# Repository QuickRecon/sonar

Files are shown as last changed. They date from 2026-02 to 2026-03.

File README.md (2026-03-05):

# Sonar



SonarMK2 is a standalone underwater sonar imaging system. An ESP32 drives a Blue Robotics Ping360 mechanical scanning sonar over RS-485, reads depth from a pressure sensor, and hosts a WiFi access point that serves a real-time polar sonar display to any browser that connects. The ESP hosts a webserver and "realtime" data is streamed over websockets, the page also uses the browser datastore to record the sonar information which can be downloaded and replayed using [text](Firmware/tools/replay.html). There is eventual intention to use the sonar for SLAM and some data analysis has occured in that direction, however this is ongoing.

## Hardware


The core is an ESP32-WROOM-32 with 2 MB flash and no PSRAM. The Ping360 communicates at 115200 baud over a half-duplex RS-485 link with automatic direction control on the DE pin. Depth comes from an MS5837-30BA pressure sensor on I2C at 400 kHz. Four status LEDs give a visual indicator of where the device is in its startup sequence.

Power input is from a battery connector (7–12 V) or USB-C, with an auto-select mux (TPS2121) handling the switch. A boost converter generates the 12 V rail for the sonar; a separate 5 V rail powers the RS-485 and external connectors. Both rails are software-controlled, so the firmware brings them up in sequence and checks power-good signals before proceeding.

The PCB also includes a CAN bus transceiver (TCAN334), the intended use is to allow for expansion to either DPV control/monitoring, or to be attached to a DiveCAN system so that rebreather information can be shown on the same display.

The hardware design files are in `EDA/` (KiCad schematic and PCB) and `CAD/` (FreeCAD housing assembly with STEP exports).

## Firmware

The firmware is built on ESP-IDF v6.0.0 and organized into nine components with no upward dependencies:

- **rs485** — UART1 half-duplex driver with automatic DE control
- **ping_protocol** — Binary frame encoder and decoder, pure C with no ESP-IDF coupling
- **ping360** — Scan task, configuration management, device probing
- **ms5837** — I2C pressure and depth sensor with full second-order compensation
- **led** — Four status LEDs indicating boot progress
- **power** — Rail enable/disable and battery voltage ADC
- **canbus** — CAN bus init and send (scaffolded, not called from main, will eventually have DiveCAN layer)
- **wifi_ap** — WiFi access point with captive portal DNS
- **web_server** — HTTPS file serving and WebSocket broadcast



### TLS Certificates

The web server uses HTTPS with a self-signed certificate. Generate the cert and key before building:

```bash
mkdir -p Firmware/certs
openssl req -x509 -newkey ec -pkeyopt ec_paramgen_curve:prime256v1 \
  -keyout Firmware/certs/server.key -out Firmware/certs/server.pem \
  -days 3650 -nodes -subj "/CN=sonar.local"
```

These files are gitignored — each device should have its own keypair.

The layering is intentional. `ping_protocol` can be compiled and tested on a host machine without any embedded toolchain. `ping360` depends on `rs485` and `ping_protocol` but knows nothing about networking. `web_server` reaches into `ping360` only for config get/set. This keeps the components independently testable and prevents the kind of circular dependency that becomes painful as a codebase grows.

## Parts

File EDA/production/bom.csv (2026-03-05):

Designator | Footprint | Quantity | Value | LCSC Part #
C1, C12, C7 | 0402 | 3 | 100n | C1525
C10, C13 | 0805 | 2 | 4.7u | C1779
C11, C16, C5 | 0603 | 3 | 10u | C96446
C14, C15 | 0402 | 2 | 100p | C1546
C17, C18, C19, C2, C6, C8, C9 | 0603 | 7 | 100n | C14663
C3, C4 | 0805 | 2 | 2.2u | C377773
D1, D2, D3, D4 | 0805 | 4 | LED | C84256
D5 | SOT-23 | 1 | PESD15VS2UT | C2831524
D6 | D_SOD-123 | 1 | MBR0520 | C5204745
F1 | Fuseholder_Littelfuse_Nano2_154x | 1 | 2A | C108518
JP1 | SolderJumper-3_P1.3mm_Bridged2Bar12_RoundedPad1.0x1.5mm | 1 | RE_MODE
L1 | L_SunItech_SLO0530H | 1 | 10u | C325966
Q1, Q2, Q4 | SOT-23 | 3 | SS8050 | C2150
Q3, Q6 | SOT-23 | 2 | SI2302 | C382300
Q5 | TSOT-23 | 1 | SI2301CDS | C10487
R1, R2, R3, R4, R9 | 0402 | 5 | 2k | C4109
R10, R12, R15, R17, R24, R26, R7, R8 | 0402 | 8 | 100k | C25741
R11, R13, R14, R16, R18, R19, R20, R5, R6 | 0402 | 9 | 10k | C25744
R21, R27 | 0402 | 2 | 12k | C25752
R22, R28, R29 | 0402 | 3 | 1.2k | C25862
R23 | 0402 | 1 | 15k | C25756
R25 | 0805 | 1 | 560 | C28636
R30 | 0603 | 1 | 2M | C22976
R31 | 0603 | 1 | 680k | C25822
U1 | QFN-28-1EP_5x5mm_P0.5mm_EP3.35x3.35mm | 1 | CP2102N-Axx-xQFN28 | C6568
U2 | Texas_VQFN-HR-12_2x2.5mm_P0.5mm | 1 | TPS2121
U3 | ESP32-WROOM-32 | 1 | ESP32-WROOM-32 | C701342
U4 | WSON-6-1EP_2x2mm_P0.65mm_EP1x1.6mm_ThermalVias | 1 | TPS7A2550DRVR | C2876265
U5 | TO-263-3_TabPin2 | 1 | LM1085-3.3 | C444380
U6 | SOT-23-5 | 1 | LMR62014XMF | C468235
U7 | SOIC-8_3.9x4.9mm_P1.27mm | 1 | TCAN334 | C2871143
U8 | SOIC-8_3.9x4.9mm_P1.27mm | 1 | ST485EBDR | C81186
U9 | TE_MS5837-xxBA | 1 | MS5837-30BA | C2887941

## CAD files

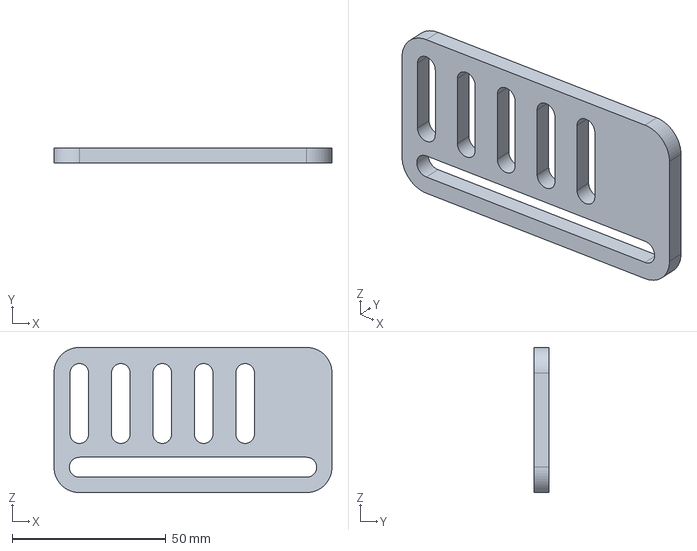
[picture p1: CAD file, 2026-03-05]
CAD/Housing.FCStd
90.5 x 5.00 x 47.2 mm

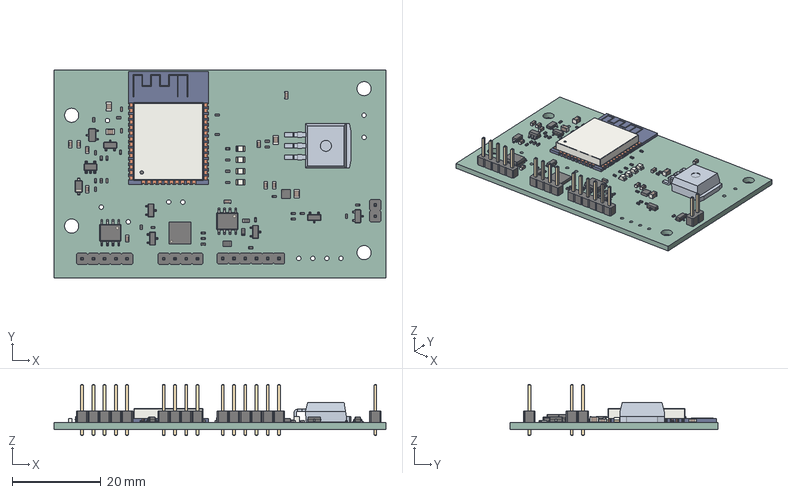
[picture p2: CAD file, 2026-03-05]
EDA/SonarMK2.step
74.9 x 47.0 x 11.5 mm
R_0402_1005Metric x 28
ESP32-WROOM-32
C_0603_1608Metric x 10
R_0805_2012Metric
LED_0805_2012Metric x 4
C_0805_2012Metric x 4
C_0402_1005Metric x 5
R_0603_1608Metric x 2
PinHeader_1x05_P2.54mm_Vertical
SOT-23 x 6
D_SOD-123
SOIC-8_3.9x4.9mm_P1.27mm x 2
TSOT-23
WSON-6-1EP_2x2mm_P0.65mm_EP1x1.6mm
PinHeader_1x06_P2.54mm_Vertical
QFN-28-1EP_5x5mm_P0.5mm_EP3.35x3.35mm
PinHeader_1x02_P2.54mm_Vertical
SonarMK2 1.64.1
SOT-23-5
PinHeader_1x04_P2.54mm_Vertical
SonarMK2_PCB

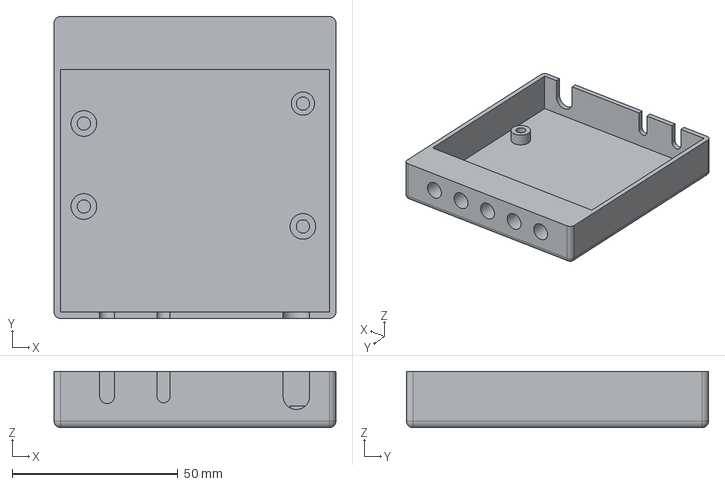
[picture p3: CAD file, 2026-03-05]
CAD/Housing-Body.step
84.9 x 91.0 x 17.0 mm

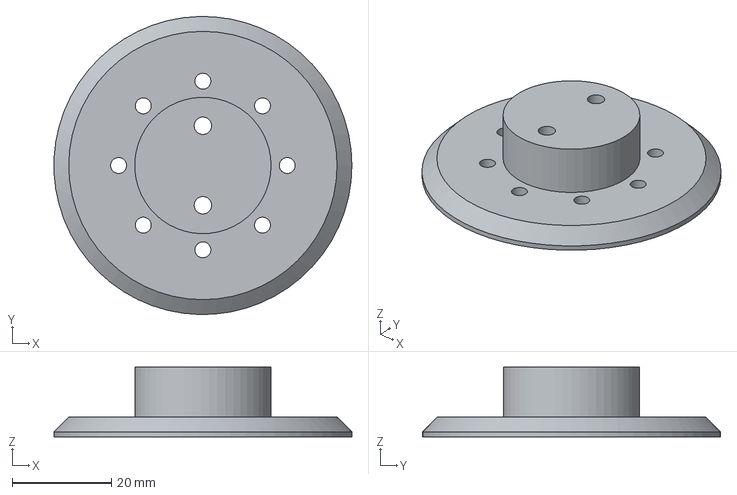
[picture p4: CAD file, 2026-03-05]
CAD/Housing-LefeetSonarMount.step
60.0 x 60.0 x 14.0 mm

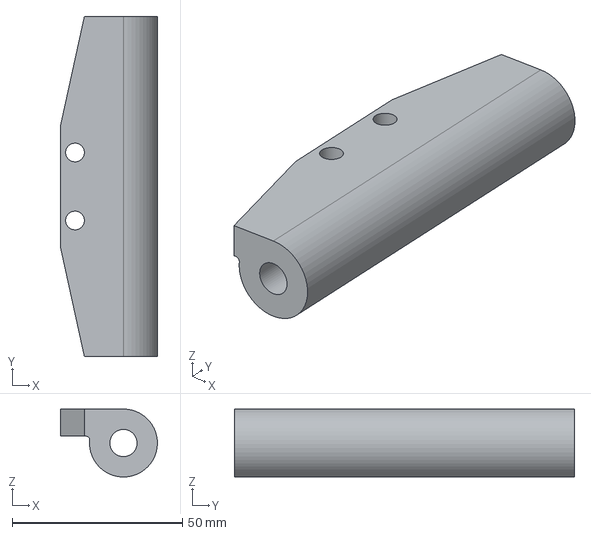
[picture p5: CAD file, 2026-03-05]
CAD/Housing-Sonar Mount.step
28.5 x 100.0 x 20.0 mm

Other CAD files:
CAD/Housing-Sideplate.step

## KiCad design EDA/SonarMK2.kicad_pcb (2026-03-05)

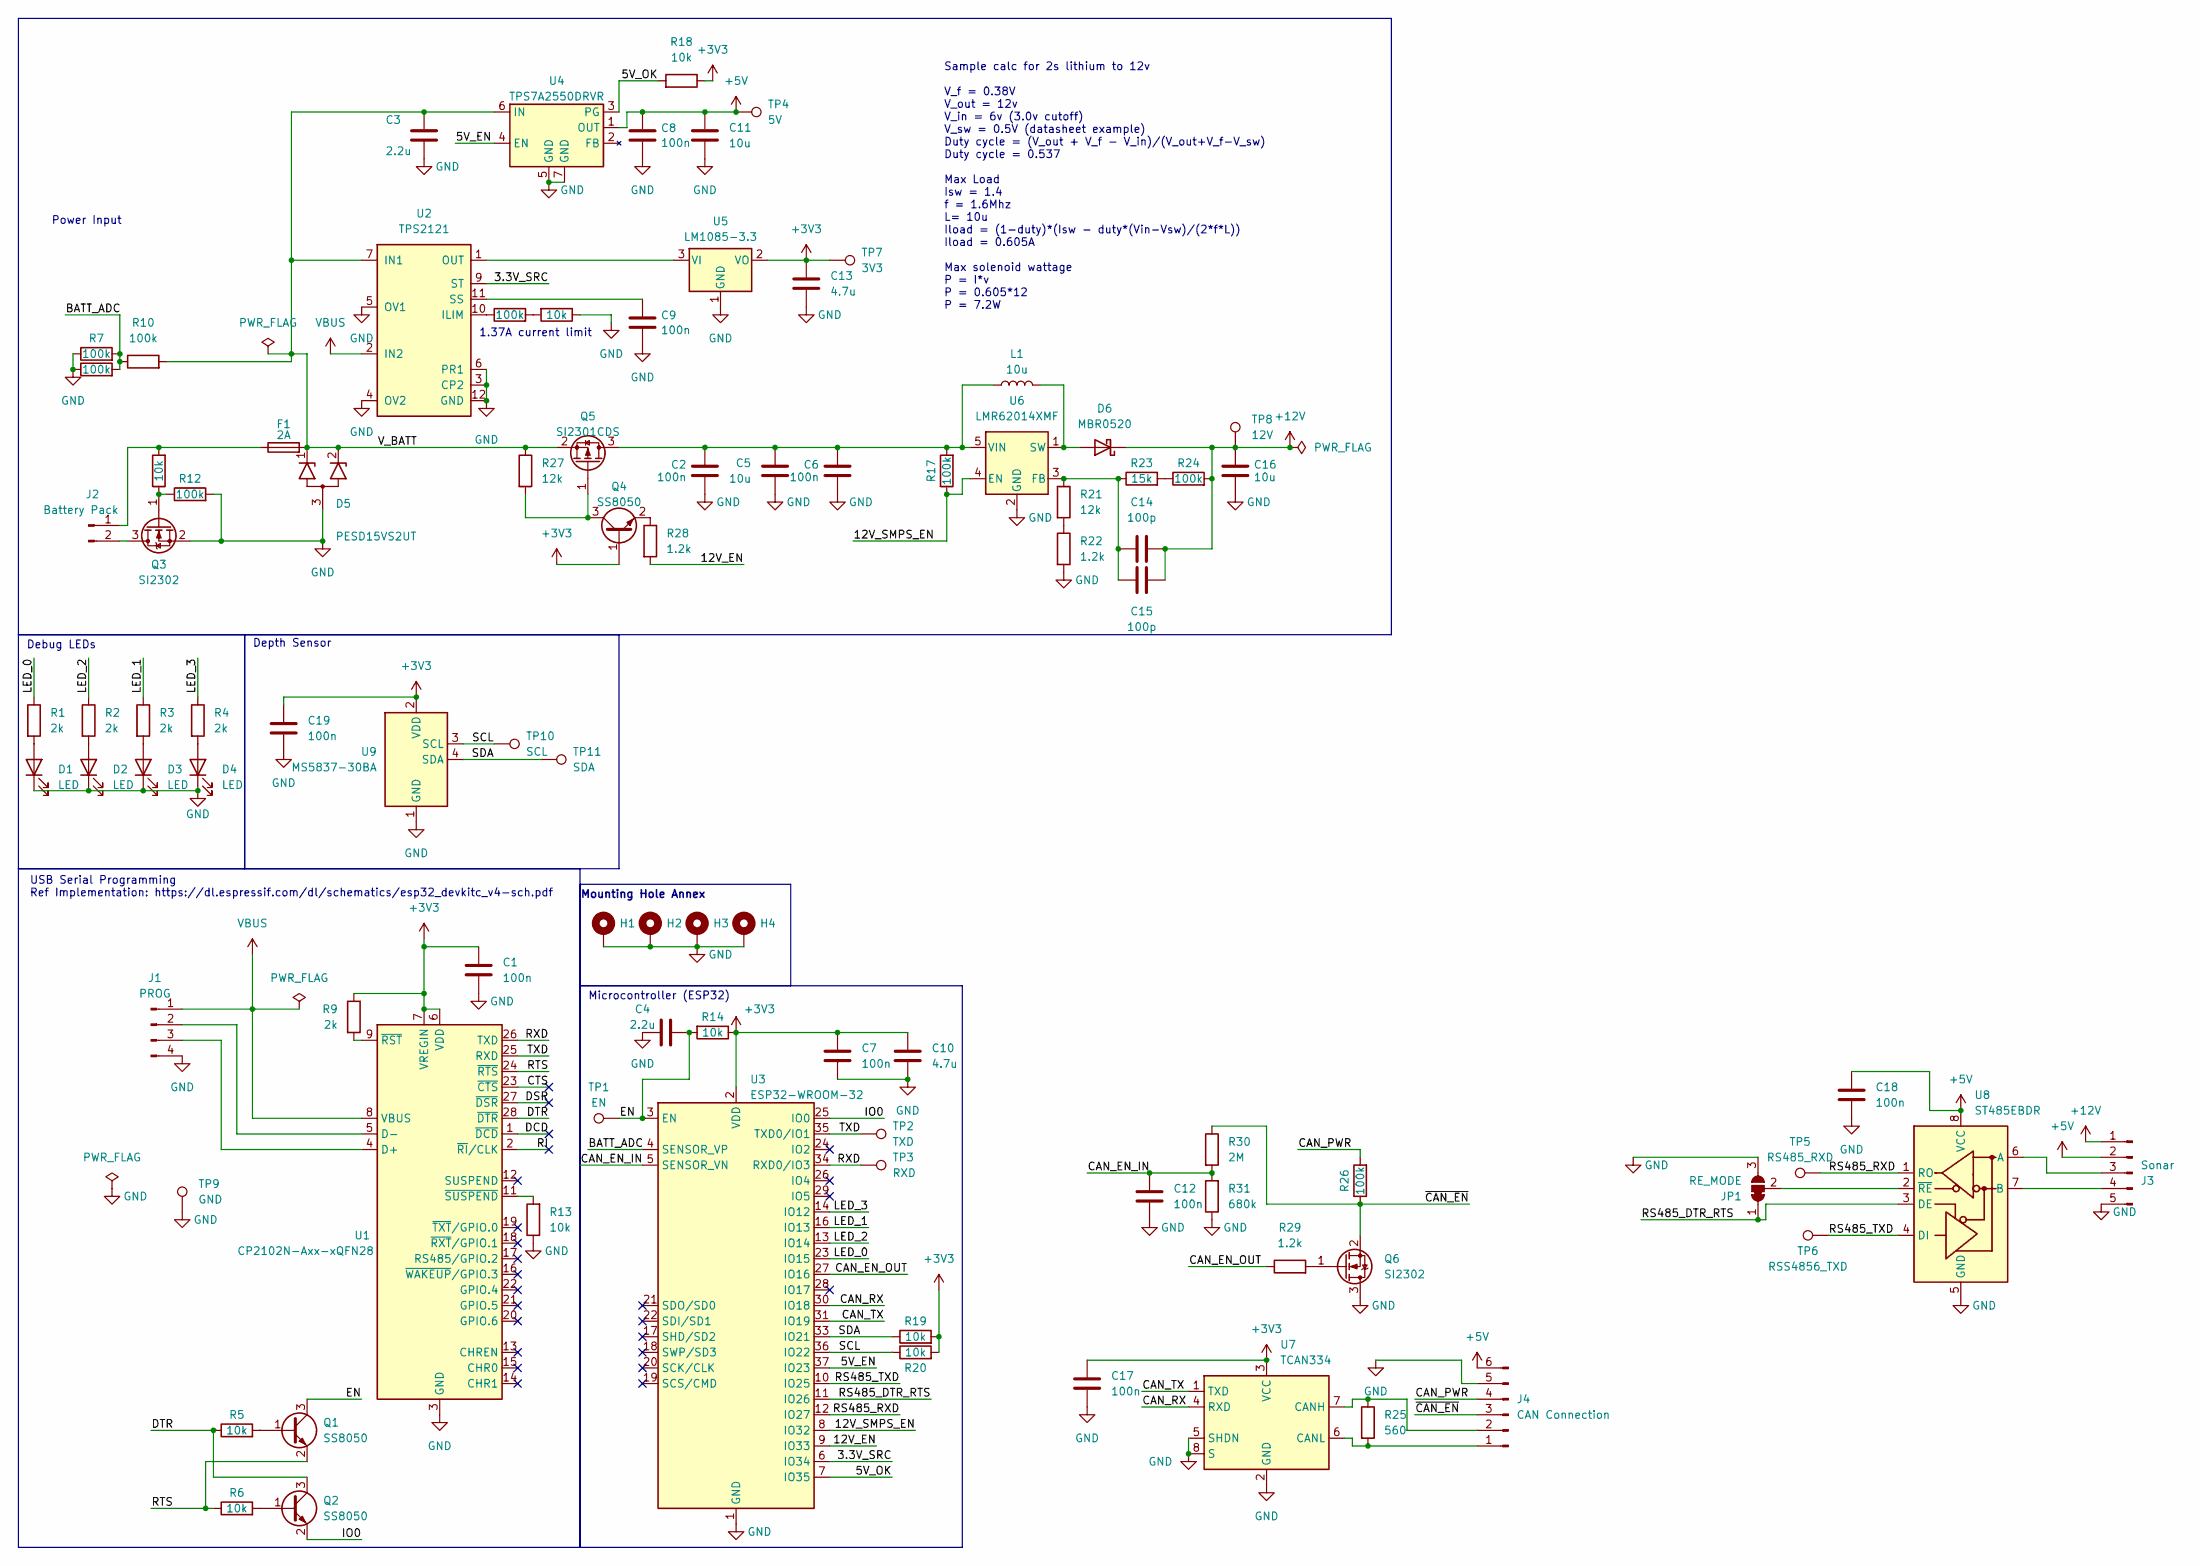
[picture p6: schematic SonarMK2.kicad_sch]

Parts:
C1, C7, C12: 100n; C_0402_1005Metric; MPN C1525
C2, C6, C8, C9, C17, C18, C19: 100n; C_0603_1608Metric; MPN C14663
C3, C4: 2.2u; C_0805_2012Metric; MPN C377773
C5, C11, C16: 10u; C_0603_1608Metric; MPN C96446
C10, C13: 4.7u; C_0805_2012Metric; MPN C1779
C14, C15: 100p; C_0402_1005Metric; MPN C1546
D1, D2, D3, D4: LED; LED_0805_2012Metric; MPN C84256
D5: PESD15VS2UT; SOT-23; MPN C2831524
D6: MBR0520; D_SOD-123; MPN C5204745
F1: 2A; Fuseholder_Littelfuse_Nano2_154x; MPN C108518
H1, H2, H3, H4: MountingHole_Pad; MountingHole_3.2mm_M3_Pad
J1: PROG; PinHeader_1x04_P2.54mm_Vertical
J2: Battery Pack; PinHeader_1x02_P2.54mm_Vertical
J3: Sonar; PinHeader_1x05_P2.54mm_Vertical
J4: CAN Connection; PinHeader_1x06_P2.54mm_Vertical
JP1: RE_MODE; SolderJumper-3_P1.3mm_Bridged2Bar12_RoundedPad1.0x1.5mm
L1: 10u; L_SunItech_SLO0530H; MPN C325966
Q1, Q2, Q4: SS8050; SOT-23; MPN C2150
Q3, Q6: SI2302; SOT-23; MPN C382300; JlcRotOffset 180
Q5: SI2301CDS; TSOT-23; MPN C10487
R1, R2, R3, R4, R9: 2k; R_0402_1005Metric; MPN C4109
R5, R6, R11, R13, R14, R16, R18, R19, R20: 10k; R_0402_1005Metric; MPN C25744
R7, R8, R10, R12, R15, R17, R24, R26: 100k; R_0402_1005Metric; MPN C25741
R21, R27: 12k; R_0402_1005Metric; MPN C25752
R22, R28, R29: 1.2k; R_0402_1005Metric; MPN C25862
R23: 15k; R_0402_1005Metric; MPN C25756
R25: 560; R_0805_2012Metric; MPN C28636
R30: 2M; R_0603_1608Metric; MPN C22976
R31: 680k; R_0603_1608Metric; MPN C25822
TP1: EN; TestPoint_THTPad_2.0x2.0mm_Drill1.0mm
TP2: TXD; TestPoint_THTPad_2.0x2.0mm_Drill1.0mm
TP3: RXD; TestPoint_THTPad_2.0x2.0mm_Drill1.0mm
TP4: 5V; TestPoint_THTPad_2.0x2.0mm_Drill1.0mm
TP5: RS485_RXD; TestPoint_THTPad_2.0x2.0mm_Drill1.0mm
TP6: RSS4856_TXD; TestPoint_THTPad_2.0x2.0mm_Drill1.0mm
TP7: 3V3; TestPoint_THTPad_2.0x2.0mm_Drill1.0mm
TP8: 12V; TestPoint_THTPad_2.0x2.0mm_Drill1.0mm
TP9: GND; TestPoint_THTPad_2.0x2.0mm_Drill1.0mm
TP10: SCL; TestPoint_THTPad_2.0x2.0mm_Drill1.0mm
TP11: SDA; TestPoint_THTPad_2.0x2.0mm_Drill1.0mm
U1: CP2102N-Axx-xQFN28; QFN-28-1EP_5x5mm_P0.5mm_EP3.35x3.35mm; MPN C6568
U2: TPS2121; Texas_VQFN-HR-12_2x2.5mm_P0.5mm; JLC Part # C485916
U3: ESP32-WROOM-32; MPN C701342
U4: TPS7A2550DRVR; WSON-6-1EP_2x2mm_P0.65mm_EP1x1.6mm_ThermalVias; MPN C2876265; JlcRotOffset 0
U5: LM1085-3.3; TO-263-3_TabPin2; MPN C444380
U6: LMR62014XMF; SOT-23-5; MPN C468235
U7: TCAN334; SOIC-8_3.9x4.9mm_P1.27mm; MPN C2871143; JlcRotOffset -90
U8: ST485EBDR; SOIC-8_3.9x4.9mm_P1.27mm; MPN C81186
U9: MS5837-30BA; TE_MS5837-xxBA; MPN C2887941

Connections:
+3V3: C1.1, C7.1, C10.1, C13.1, C17.1, C19.1, Q4.1 (B), R9.1, R14.1, R18.1, R19.2, R20.2, TP7.1, U1.6 (VDD), U1.7 (VREGIN), U3.2 (VDD), U5.2 (VO), U7.3 (VCC), U9.2 (VDD)
+5V: C8.1, C11.1, C18.1, J3.2, J4.6, TP4.1, U4.1 (OUT), U8.8 (VCC)
+12V: C14.1, C15.1, C16.1, D6.1 (K), J3.1, R24.2, TP8.1
/3.3V_SRC: U2.9 (ST), U3.6 (IO34)
/5V_EN: U3.37 (IO23), U4.4 (EN)
/5V_OK: R18.2, U3.7 (IO35), U4.3 (PG)
/12V_EN: R28.2, U3.9 (IO33)
/12V_SMPS_EN: R17.1, U3.8 (IO32), U6.4 (EN)
/BATT_ADC: R7.2, R8.2, R10.1, U3.4 (SENSOR_VP)
/CAN_EN_IN: C12.1, R30.2, R31.2, U3.5 (SENSOR_VN)
/CAN_EN_OUT: R29.1, U3.27 (IO16)
/CAN_PWR: J4.4, R26.2
/CAN_RX: U3.30 (IO18), U7.4 (RXD)
/CAN_TX: U3.31 (IO19), U7.1 (TXD)
/CTS: U1.23 (~CTS)
/DCD: U1.1 (~DCD)
/DSR: U1.27 (~DSR)
/DTR: Q2.3 (C), R5.1, U1.28 (~DTR)
/EN: C4.2, Q1.3 (C), R14.2, TP1.1, U3.3 (EN)
/IO0: Q2.2 (E), U3.25 (IO0)
/LED_0: R1.1, U3.23 (IO15)
/LED_1: R3.1, U3.16 (IO13)
/LED_2: R2.1, U3.13 (IO14)
/LED_3: R4.1, U3.14 (IO12)
/RI: U1.2 (~RI/CLK)
/RS485_DTR_RTS: JP1.1 (A), U3.11 (IO26), U8.3 (DE)
/RS485_RXD: TP5.1, U3.12 (IO27), U8.1 (RO)
/RS485_TXD: TP6.1, U3.10 (IO25), U8.4 (DI)
/RTS: Q1.2 (E), R6.1, U1.24 (~RTS)
/RXD: TP3.1, U1.26 (TXD), U3.34 (RXD0/IO3)
/SCL: R20.1, TP10.1, U3.36 (IO22), U9.3 (SCL)
/SDA: R19.1, TP11.1, U3.33 (IO21), U9.4 (SDA)
/TXD: TP2.1, U1.25 (RXD), U3.35 (TXD0/IO1)
/V_BATT: C3.1, D5.1 (K1), D5.2 (K2), F1.2, Q5.2 (S), R10.2, R27.1, U2.7 (IN1), U4.6 (IN)
/~CAN_EN: J4.3, Q6.2 (S), R26.1, R30.1
GND: C1.2, C2.1, C3.2, C4.1, C5.2, C6.1, C7.2, C8.2, C9.2, C10.2, C11.2, C12.2, C13.2, C16.2, C17.2, C18.2, C19.2, D1.1 (K), D2.1 (K), D3.1 (K), D4.1 (K), D5.3 (A), H1.1, H2.1, H3.1, H4.1, J1.4, J3.5, J4.5, JP1.3 (B), Q3.2 (S), Q6.3 (D), R7.1, R8.1, R12.2, R13.1, R16.1, R22.2, R31.1, TP9.1, U1.3 (GND), U1.29 (GND), U2.3 (CP2), U2.4 (OV2), U2.5 (OV1), U2.6 (PR1), U2.12 (GND), U3.1 (GND), U3.15 (GND), U3.38 (GND), U3.39 (GND), U4.5 (GND), U4.7 (GND), U5.1 (GND), U6.2 (GND), U7.2 (GND), U7.5 (SHDN), U7.8 (S), U8.5 (GND), U9.1 (GND)
unnamed: D1.2 (A), R1.2
unnamed: D2.2 (A), R2.2
unnamed: D3.2 (A), R3.2
unnamed: D4.2 (A), R4.2
unnamed: D6.2 (A), L1.2, U6.1 (SW)
unnamed: J1.2, U1.5 (D-)
unnamed: J1.3, U1.4 (D+)
unnamed: F1.1, J2.1, R11.2
unnamed: J2.2, Q3.3 (D)
unnamed: J3.3, U8.6 (A)
unnamed: J3.4, U8.7 (B)
unnamed: J4.1, R25.2, U7.6 (CANL)
unnamed: J4.2, R25.1, U7.7 (CANH)
unnamed: JP1.2 (C), U8.2 (~RE)
unnamed: Q1.1 (B), R5.2
unnamed: Q2.1 (B), R6.2
unnamed: Q3.1 (G), R11.1, R12.1
unnamed: Q4.3 (C), Q5.1 (G), R27.2
unnamed: Q4.2 (E), R28.1
unnamed: C2.2, C5.1, C6.2, L1.1, Q5.3 (D), R17.2, U6.5 (VIN)
unnamed: Q6.1 (G), R29.2
unnamed: R15.2, R16.2
unnamed: R21.2, R22.1
unnamed: R23.2, R24.1
unnamed: R9.2, U1.9 (~RST)
unnamed: R13.2, U1.11 (~SUSPEND)
unnamed: R15.1, U2.10 (ILIM)
unnamed: C9.1, U2.11 (SS)
unnamed: U2.1 (OUT), U2.8 (OUT), U5.3 (VI)
unnamed: C14.2, C15.2, R21.1, R23.1, U6.3 (FB)
VBUS: J1.1, U1.8 (VBUS), U2.2 (IN2)

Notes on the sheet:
Power Input
1.37A current limit
Depth Sensor
USB Serial Programming Ref Implementation: https://dl.espressif.com/dl/schematics/esp32_devkitc_v4-sch.pdf
Sample calc for 2s lithium to 12v V_f = 0.38V V_out = 12v V_in = 6v (3.0v cutoff) V_sw = 0.5V (datasheet example) Duty cycle = (V_out + V_f - V_in)/(V_out+V_f-V_sw) Duty cycle = 0.537 Max Load Isw = 1.4 f = 1.6Mhz L= 10u Iload = (1-duty)*(Isw - duty*(Vin-Vsw)/(2*f*L)) Iload = 0.605A Max solenoid wa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
Debug LEDs
Microcontroller (ESP32)
Mounting Hole Annex

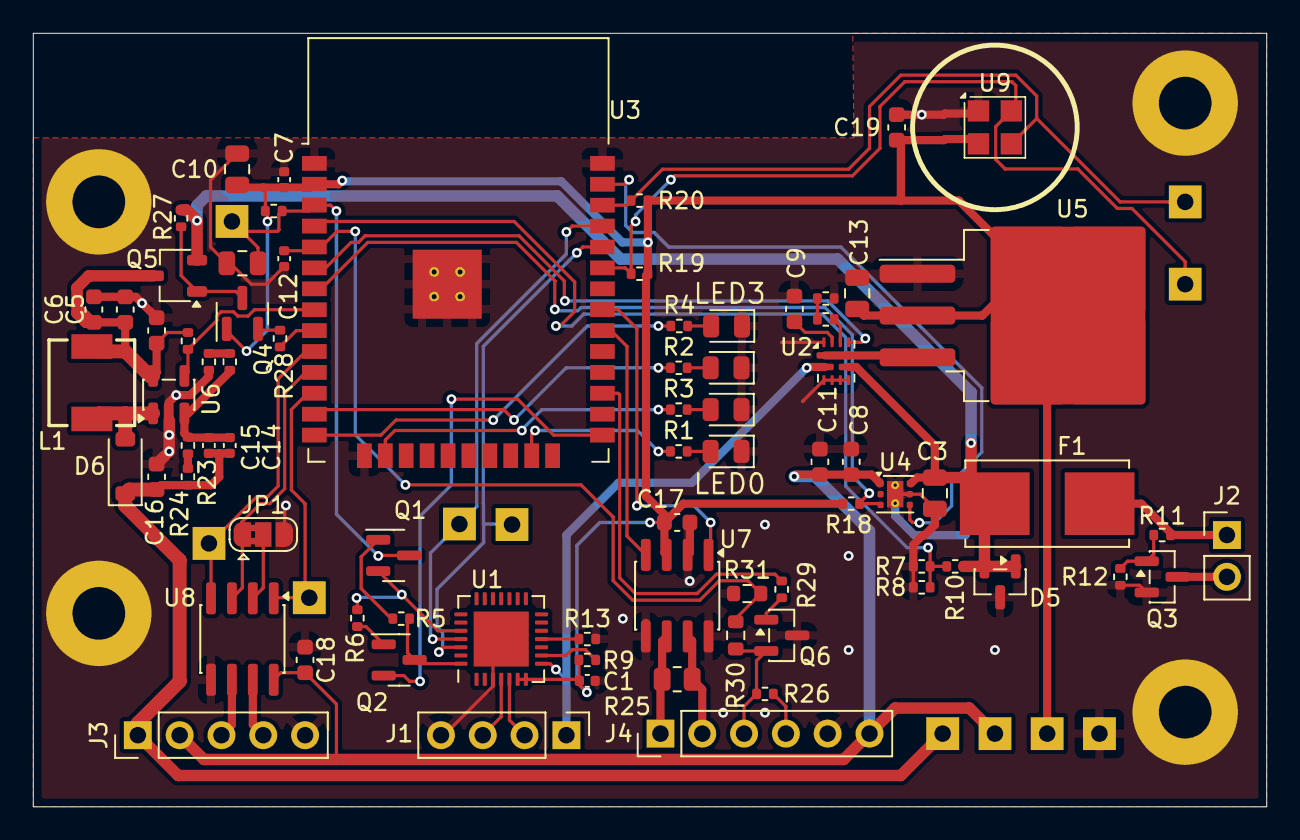
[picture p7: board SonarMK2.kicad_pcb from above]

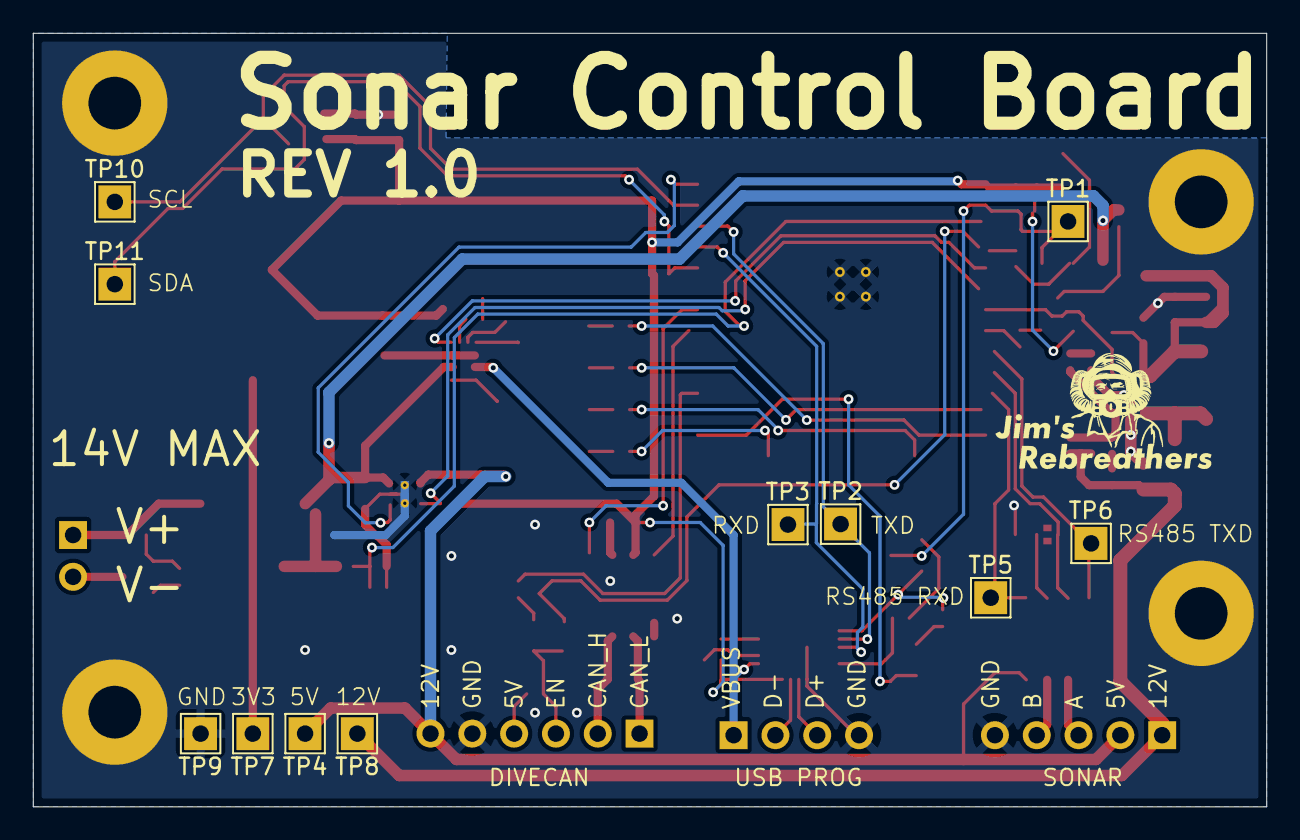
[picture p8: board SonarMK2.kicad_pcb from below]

Board: 2 copper layers, 74.9 x 47.0 mm, 93 parts (11 on the bottom side), 63 nets.

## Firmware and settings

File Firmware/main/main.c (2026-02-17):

#include <stdio.h>
#include <string.h>
#include <math.h>
#include "freertos/FreeRTOS.h"
#include "freertos/task.h"
#include "nvs_flash.h"
#include "nvs.h"
#include "esp_netif.h"
#include "esp_event.h"
#include "esp_log.h"
#include "esp_heap_caps.h"
#include "driver/i2c_master.h"

#include "led.h"
#include "power.h"
#include "rs485.h"
#include "ping360.h"
#include "ms5837.h"
#include "wifi_ap.h"
#include "mdns_service.h"
#include "web_server.h"

/* Set to 0 to disable periodic heap/task diagnostics */
#define ENABLE_DIAG 0

#define NVS_CFG_NAMESPACE  "sonar_cfg"
#define NVS_CFG_KEY        "cfg"
#define NVS_CFG_VERSION    1
#define BOOTLOOP_NAMESPACE "bootloop"
#define BOOTLOOP_THRESHOLD 3

static const char *TAG = "main";

/* Calculate speed of sound in water (m/s).
 * Freshwater: Marczak (1997) simplified.
 * Saltwater:  Mackenzie (1981) at 35 PSU. */
static uint16_t calculate_speed_of_sound(float temp_c, float depth_m,
                                         bool saltwater)
{
    float c;
    if (saltwater) {
        /* Mackenzie (1981), S=35 PSU */
        c = 1448.96f + 4.591f * temp_c
            - 0.05304f * temp_c * temp_c
            + 0.0002374f * temp_c * temp_c * temp_c
            + 0.016f * depth_m;
    } else {
        /* Marczak (1997) simplified */
        c = 1402.7f + 5.0f * temp_c
            - 0.055f * temp_c * temp_c
            + 0.0003f * temp_c * temp_c * temp_c;
    }
    return (uint16_t)(c + 0.5f);
}

static void sonar_data_callback(uint16_t angle, const uint8_t *data,
                                uint16_t num_samples, void *user_ctx)
{
    web_server_broadcast_sonar(angle, data, num_samples);
}

void app_main(void)
{
    /* 1. LEDs */
    ESP_ERROR_CHECK(led_init());
    led_set(LED_ID_0, true);
    ESP_LOGI(TAG, "Booting...");

    /* 2-4. Power management */
    ESP_ERROR_CHECK(power_init());
    ESP_ERROR_CHECK(power_5v_enable(true));
    vTaskDelay(pdMS_TO_TICKS(10));
    if (!power_5v_ok()) {
        ESP_LOGW(TAG, "5V rail not reporting OK");
    }
    ESP_ERROR_CHECK(power_12v_enable(true));
    vTaskDelay(pdMS_TO_TICKS(50));
    led_set(LED_ID_1, true);
    ESP_LOGI(TAG, "Power rails enabled");

    /* 6-7. NVS + network stack */
    esp_err_t ret = nvs_flash_init();
    if (ret == ESP_ERR_NVS_NO_FREE_PAGES ||
        ret == ESP_ERR_NVS_NEW_VERSION_FOUND) {
        ESP_ERROR_CHECK(nvs_flash_erase());
        ret = nvs_flash_init();
    }
    ESP_ERROR_CHECK(ret);
    ESP_ERROR_CHECK(esp_netif_init());
    ESP_ERROR_CHECK(esp_event_loop_create_default());

    /* Bootloop detection: if we crash 3 times before reaching stable state,
     * wipe saved settings on the next boot */
    {
        nvs_handle_t nvs;
        if (nvs_open(BOOTLOOP_NAMESPACE, NVS_READWRITE, &nvs) == ESP_OK) {
            uint8_t boot_count = 0;
            nvs_get_u8(nvs, "count", &boot_count);
            if (boot_count >= BOOTLOOP_THRESHOLD) {
                ESP_LOGW(TAG, "Bootloop detected (%u crashes) — resetting settings",
                         boot_count);
                nvs_erase_all(nvs);
                nvs_commit(nvs);
                /* Erase saved config and depth calibration */
                nvs_handle_t cfg_nvs;
                if (nvs_open(NVS_CFG_NAMESPACE, NVS_READWRITE, &cfg_nvs) == ESP_OK) {
                    nvs_erase_all(cfg_nvs);
                    nvs_commit(cfg_nvs);
                    nvs_close(cfg_nvs);
                }
                nvs_handle_t cal_nvs;
                if (nvs_open("depth_cal", NVS_READWRITE, &cal_nvs) == ESP_OK) {
                    nvs_erase_all(cal_nvs);
                    nvs_commit(cal_nvs);
                    nvs_close(cal_nvs);
                }
            } else {
                boot_count++;
                nvs_set_u8(nvs, "count", boot_count);
                nvs_commit(nvs);
            }
            nvs_close(nvs);
        }
    }

    /* Load saved atmospheric pressure calibration from NVS */
    float atmo_pressure_mbar = 1013.25f;
    {
        nvs_handle_t nvs;
        if (nvs_open("depth_cal", NVS_READONLY, &nvs) == ESP_OK) {
            uint32_t raw = 0;
            if (nvs_get_u32(nvs, "atmo_mbar", &raw) == ESP_OK) {
                memcpy(&atmo_pressure_mbar, &raw, sizeof(float));
                ESP_LOGI(TAG, "Loaded atmo pressure from NVS: %.1f mbar",
                         atmo_pressure_mbar);
            }
            nvs_close(nvs);
        }
    }

    /* 8-9. I2C + MS5837 */
    i2c_master_bus_config_t i2c_cfg = {
        .clk_source = I2C_CLK_SRC_DEFAULT,
        .i2c_port = I2C_NUM_0,
        .sda_io_num = MS5837_SDA_PIN,
        .scl_io_num = MS5837_SCL_PIN,
        .glitch_ignore_cnt = 7,
        .flags.enable_internal_pullup = true,
    };
    i2c_master_bus_handle_t i2c_bus = NULL;
    ESP_ERROR_CHECK(i2c_new_master_bus(&i2c_cfg, &i2c_bus));

    ms5837_t depth_sensor = {0};
    bool depth_ok = false;
    ret = ms5837_init(i2c_bus, &depth_sensor);
    if (ESP_OK == ret) {
        depth_ok = true;
        ms5837_set_atmo_pressure(&depth_sensor, atmo_pressure_mbar);
        ESP_LOGI(TAG, "MS5837 depth sensor initialized");
    } else {
        ESP_LOGW(TAG, "MS5837 init failed: %s (continuing without depth)",
                 esp_err_to_name(ret));
    }

    /* 10-12. RS-485 + Ping360 */
    ESP_ERROR_CHECK(rs485_init());
    ESP_ERROR_CHECK(ping360_init());

    /* Restore saved sonar config from NVS (if any) */
    {
        nvs_handle_t nvs;
        if (nvs_open(NVS_CFG_NAMESPACE, NVS_READONLY, &nvs) == ESP_OK) {
            uint8_t blob[1 + sizeof(ping360_config_t)];
            size_t len = sizeof(blob);
            if (nvs_get_blob(nvs, NVS_CFG_KEY, blob, &len) == ESP_OK &&
                len == sizeof(blob) && blob[0] == NVS_CFG_VERSION) {
                ping360_config_t cfg;
                memcpy(&cfg, &blob[1], sizeof(cfg));
                ping360_set_config(&cfg);
                ESP_LOGI(TAG, "Restored sonar config from NVS");
            }
            nvs_close(nvs);
        }
    }

    bool sonar_found = ping360_probe(2000);
    if (sonar_found) {
        led_set(LED_ID_2, true);
        ESP_LOGI(TAG, "Ping360 sonar detected");
    } else {
        ESP_LOGW(TAG, "Ping360 not detected (will retry during scan)");
    }

    /* 13-15. WiFi + mDNS + Web server */
    ESP_ERROR_CHECK(wifi_ap_init());
    ESP_ERROR_CHECK(mdns_service_init());
    ESP_ERROR_CHECK(web_server_init());

    /* Mark boot as stable — reset bootloop counter */
    {
        nvs_handle_t nvs;
        if (nvs_open(BOOTLOOP_NAMESPACE, NVS_READWRITE, &nvs) == ESP_OK) {
            nvs_set_u8(nvs, "count", 0);
            nvs_commit(nvs);
            nvs_close(nvs);
        }
    }

    /* 15-16. Start sonar scan */
    ping360_register_data_callback(sonar_data_callback, NULL);
    ESP_ERROR_CHECK(ping360_start_scan());

    /* 17. All systems go */
    led_set(LED_ID_3, true);
    ESP_LOGI(TAG, "SonarMK2 ready");

    /* 18. Sensor poll loop (1 Hz) */
#if ENABLE_DIAG
    int diag_counter = 0;
#endif
    while (1) {
        vTaskDelay(pdMS_TO_TICKS(1000));

#if ENABLE_DIAG
        /* Periodic diagnostics (every 10s) */
        if (++diag_counter >= 10) {
            diag_counter = 0;

            size_t free_heap = esp_get_free_heap_size();
            size_t min_free = esp_get_minimum_free_heap_size();
            size_t largest_blk = heap_caps_get_largest_free_block(MALLOC_CAP_DEFAULT);
            ESP_LOGI(TAG, "Heap: free=%u min_ever=%u largest_block=%u",
                     free_heap, min_free, largest_blk);

            UBaseType_t num_tasks = uxTaskGetNumberOfTasks();
            TaskStatus_t *tasks = malloc(num_tasks * sizeof(TaskStatus_t));
            if (tasks) {
                uint32_t total_runtime;
                UBaseType_t n = uxTaskGetSystemState(tasks, num_tasks,
                                                     &total_runtime);
                ESP_LOGI(TAG, "Tasks (%u):", n);
                for (UBaseType_t i = 0; i < n; i++) {
                    float cpu_pct = 0;
                    if (total_runtime > 0) {
                        cpu_pct = (tasks[i].ulRunTimeCounter * 100.0f)
                                  / total_runtime;
                    }
                    const char *st;
                    switch (tasks[i].eCurrentState) {
                        case eRunning:   st = "RUN"; break;
                        case eReady:     st = "RDY"; break;
                        case eBlocked:   st = "BLK"; break;
                        case eSuspended: st = "SUS"; break;
                        case eDeleted:   st = "DEL"; break;
                        default:         st = "???"; break;
                    }
                    ESP_LOGI(TAG, "  %-16s %s prio=%-2u stk_free=%-5u cpu=%.1f%%",
                             tasks[i].pcTaskName, st,
                             tasks[i].uxCurrentPriority,
                             tasks[i].usStackHighWaterMark,
                             cpu_pct);
                }
                free(tasks);
            }
        }
#endif

        float depth = 0, temp = 0, pressure = 0;
        if (depth_ok) {
            ret = ms5837_read(&depth_sensor);
            if (ret == ESP_OK) {
                depth = ms5837_get_depth(&depth_sensor);
                temp = ms5837_get_temperature(&depth_sensor);
                pressure = ms5837_get_pressure(&depth_sensor);
            }
        }

        /* Zero depth calibration: use current pressure as atmospheric ref */
        if (depth_ok && web_server_check_zero_depth()) {
            atmo_pressure_mbar = pressure;
            ms5837_set_atmo_pressure(&depth_sensor, atmo_pressure_mbar);
            depth = ms5837_get_depth(&depth_sensor);
            ESP_LOGI(TAG, "Depth zeroed: atmo=%.1f mbar", atmo_pressure_mbar);

            nvs_handle_t nvs;
            if (nvs_open("depth_cal", NVS_READWRITE, &nvs) == ESP_OK) {
                uint32_t raw;
                memcpy(&raw, &atmo_pressure_mbar, sizeof(float));
                nvs_set_u32(nvs, "atmo_mbar", raw);
                nvs_commit(nvs);
                nvs_close(nvs);
            }
        }

        /* Save sonar config to NVS when changed from web UI */
        if (web_server_check_config_changed()) {
            ping360_config_t save_cfg;
            ping360_get_config(&save_cfg);
            uint8_t blob[1 + sizeof(ping360_config_t)];
            blob[0] = NVS_CFG_VERSION;
            memcpy(&blob[1], &save_cfg, sizeof(save_cfg));
            nvs_handle_t nvs;
            if (nvs_open(NVS_CFG_NAMESPACE, NVS_READWRITE, &nvs) == ESP_OK) {
                nvs_set_blob(nvs, NVS_CFG_KEY, blob, sizeof(blob));
                nvs_commit(nvs);
                nvs_close(nvs);
                ESP_LOGI(TAG, "Sonar config saved to NVS");
            }
        }

        /* Reset all settings to factory defaults */
        if (web_server_check_reset_settings()) {
            ESP_LOGI(TAG, "Resetting all settings to defaults");
            /* Erase saved config */
            nvs_handle_t nvs;
            if (nvs_open(NVS_CFG_NAMESPACE, NVS_READWRITE, &nvs) == ESP_OK) {
                nvs_erase_all(nvs);
                nvs_commit(nvs);
                nvs_close(nvs);
            }
            /* Erase depth calibration */
            if (nvs_open("depth_cal", NVS_READWRITE, &nvs) == ESP_OK) {
                nvs_erase_all(nvs);
                nvs_commit(nvs);
                nvs_close(nvs);
            }
            /* Reset runtime state */
            ping360_reset_config();
            atmo_pressure_mbar = 1013.25f;
            ms5837_set_atmo_pressure(&depth_sensor, atmo_pressure_mbar);
            web_server_broadcast_config();
        }

        /* Update speed of sound from current temperature + water type */
        ping360_config_t cfg;
        ping360_get_config(&cfg);
        uint16_t new_sos = calculate_speed_of_sound(temp, depth, cfg.saltwater);
        if (new_sos != cfg.speed_of_sound) {
            cfg.speed_of_sound = new_sos;
            ping360_set_config(&cfg);
        }

        int batt_mv = power_read_battery_mv();
        float scan_rate = ping360_get_scan_rate();

        web_server_broadcast_status(depth, temp, pressure, batt_mv,
                                    scan_rate, sonar_found);
    }
}

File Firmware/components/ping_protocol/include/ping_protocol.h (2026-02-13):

#pragma once

#include <stddef.h>
#include <stdint.h>

#define PING_MSG_GENERAL_REQUEST   6
#define PING_MSG_PROTOCOL_VERSION  5
#define PING_MSG_TRANSDUCER        2601
#define PING_MSG_DEVICE_DATA       2300
#define PING_MSG_MOTOR_OFF         2903

#define PING_FRAME_HEADER_LEN  8
#define PING_FRAME_CHECKSUM_LEN 2
#define PING_MAX_PAYLOAD_LEN   1220
#define PING_MAX_FRAME_LEN     (PING_FRAME_HEADER_LEN + PING_MAX_PAYLOAD_LEN + PING_FRAME_CHECKSUM_LEN)

#define PING_SRC_ID  0
#define PING_DST_ID  0

typedef struct {
    uint8_t  mode;
    uint8_t  gain;
    uint16_t angle;
    uint16_t transmit_duration;
    uint16_t sample_period;
    uint16_t transmit_frequency;
    uint16_t num_samples;
    uint8_t  transmit;
} ping_transducer_cmd_t;

typedef struct {
    uint8_t  mode;
    uint8_t  gain;
    uint16_t angle;
    uint16_t transmit_duration;
    uint16_t sample_period;
    uint16_t transmit_frequency;
    uint16_t num_samples;
    const uint8_t *data;
    uint16_t data_len;
} ping_device_data_t;

typedef enum {
    PING_PARSE_START1,
    PING_PARSE_START2,
    PING_PARSE_LEN_L,
    PING_PARSE_LEN_H,
    PING_PARSE_ID_L,
    PING_PARSE_ID_H,
    PING_PARSE_SRC,
    PING_PARSE_DST,
    PING_PARSE_PAYLOAD,
    PING_PARSE_CHK_L,
    PING_PARSE_CHK_H,
} ping_parse_state_t;

typedef struct {
    ping_parse_state_t state;
    uint8_t buf[PING_MAX_FRAME_LEN];
    uint16_t payload_len;
    uint16_t msg_id;
    uint16_t payload_idx;
    uint16_t checksum;
    uint16_t rx_checksum;
} ping_parser_t;

int ping_build_frame(uint8_t *buf, size_t buf_size, uint16_t msg_id,
                     const uint8_t *payload, uint16_t payload_len);
int ping_build_transducer_cmd(uint8_t *buf, size_t buf_size,
                              const ping_transducer_cmd_t *cmd);
int ping_build_general_request(uint8_t *buf, size_t buf_size,
                               uint16_t requested_id);
int ping_build_motor_off(uint8_t *buf, size_t buf_size);

void ping_parser_init(ping_parser_t *parser);
int ping_parser_feed(ping_parser_t *parser, uint8_t byte);
int ping_parse_device_data(const ping_parser_t *parser,
                           ping_device_data_t *out);

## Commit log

2026-02-11 Initial clauding
    [partitions.csv]
2026-02-13 Get rid of spiffs to better support ota later
    [partitions.csv]
2026-02-13 Add sonar datastore
2026-02-13 Enable snapping to angles
    [rs485.c]
2026-02-14 Improve power sequencing
2026-02-14 Add some robustification to the sockets
2026-02-14 Change 500 samples to 600 samples to avoid sonar firmware issue
2026-02-16 Add depth zero button
2026-02-19 Fix depth sensor overreading
    [ms5837.c]
2026-03-05 Add CAD, EDA, and project docs to version control
    Move git root from Firmware/ to SonarMK2/ and bring CAD (FreeCAD) and
    EDA (KiCAD) design files under version control alongside firmware.
    [Housing-Body.step, Housing-LefeetSonarMount.step, Housing-Sideplate.step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]
